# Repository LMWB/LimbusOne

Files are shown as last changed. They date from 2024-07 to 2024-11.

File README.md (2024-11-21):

# LimbusOne
Custom Microcontroller Board based on STM32F042-Series

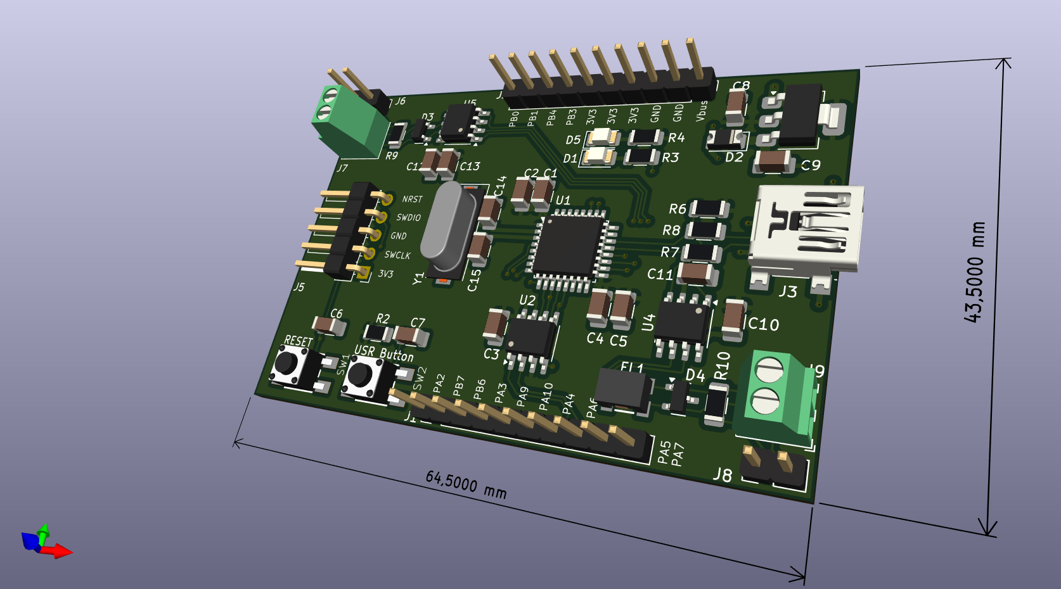
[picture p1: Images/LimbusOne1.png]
front

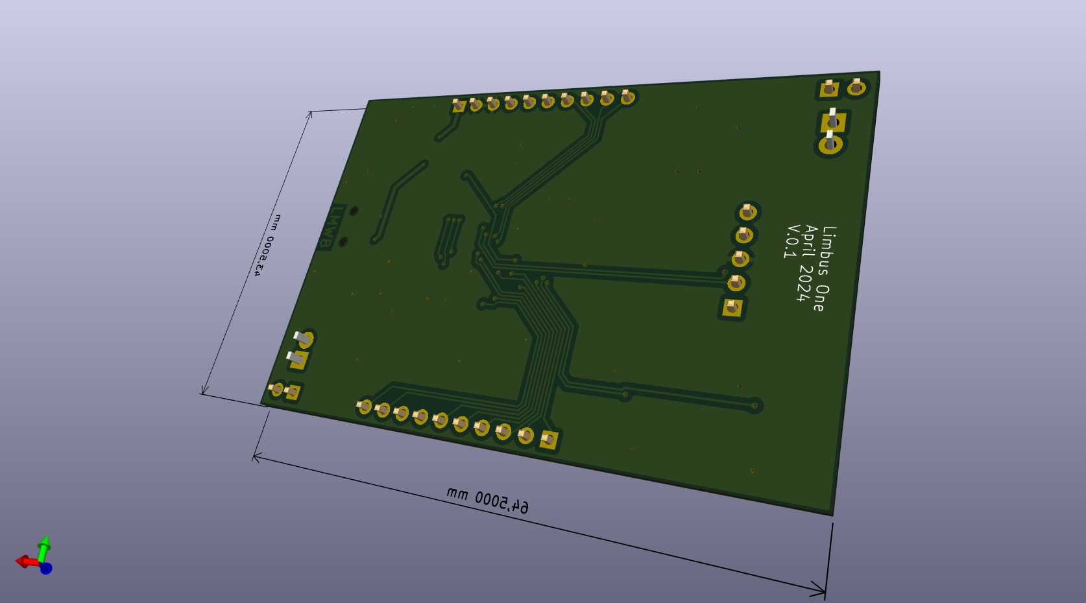
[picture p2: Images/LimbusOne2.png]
back

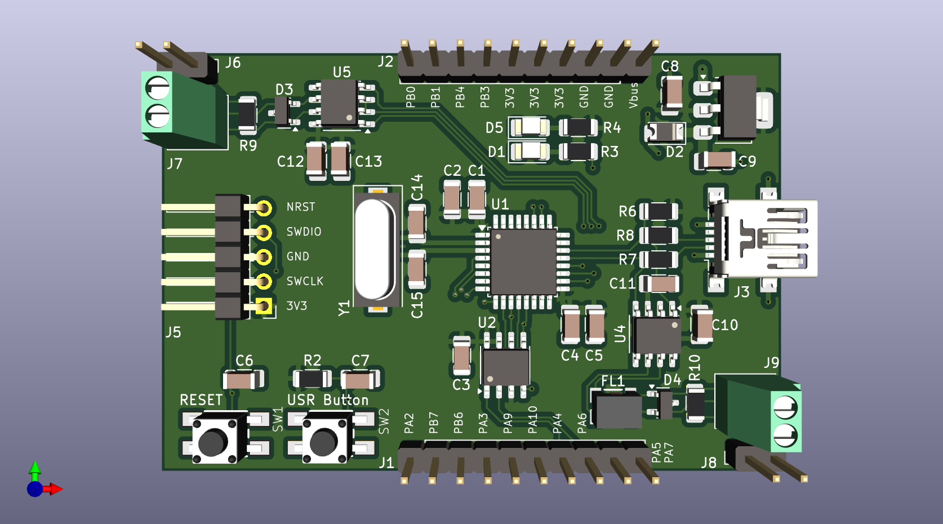
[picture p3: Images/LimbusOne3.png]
top

[schematics](/Hardware/LimbusOne/PDF/LimbusOne.pdf)

 Features
- STM32F042K6T6 Microcontroller
- it got a crystal oscillator but I did not use it
    - accuracy is good since USB Data is working
- Power indicator LED
- User LED
- User Push Button
- Industrial ready CAN-Bus interface
    - works with standard (11-Bit) and extended (29-Bit) CAN identifier
- Industrial ready Modbus interface
- USB mini as power supply AND DATA
    - unfortunately USB and CAN share same Pin's so the user has to decide what to use
- 2.54mm Pin Headers for debugging and tracing
- debug / programming interface according to STLink that comes with most of STM32 Nucleo Boards

# Todo
- adjust Pin Header spacing to a more usable spacing, right know its pretty random

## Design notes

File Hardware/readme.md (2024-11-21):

here you can find the KiCad EDA project files

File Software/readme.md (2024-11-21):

Here you can find some cubeIDE stand alone projects to test the hardware.
- basic to test flash capability Button, LED and Reset
- USB
- RS485 / Modbus
- CAN

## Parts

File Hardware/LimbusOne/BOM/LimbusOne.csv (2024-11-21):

Reference | Value | Footprint | Qty | DNP
C1,C4,C11,C13 | 47u | Capacitor_SMD:C_1206_3216Metric | 4
C2,C3,C5,C6,C7,C10,C12 | 100n | Capacitor_SMD:C_1206_3216Metric | 7
C8,C9 | 1u | Capacitor_SMD:C_1206_3216Metric | 2
C14,C15 | 22p | Capacitor_SMD:C_1206_3216Metric | 2
D1,D5 | LED | LED_SMD:LED_1206_3216Metric | 2
D2 | D | Diode_SMD:D_1206_3216Metric | 1
D3,D4 | NUP2105L | Package_TO_SOT_SMD:SOT-23 | 2
FL1 | Filter_CAN_Choke_LL_1234 | LMWB_footprints:WE-CNSW_1812 | 1
J1,J2 | Conn_01x10 | Connector_PinHeader_2.54mm:PinHeader_1x10_P2.54mm_Vertical | 2
J3 | USB_B_Micro | Connector_USB:USB_Mini-B_Lumberg_2486_01_Horizontal | 1
J5 | Conn_01x05 | Connector_PinHeader_2.54mm:PinHeader_1x05_P2.54mm_Horizontal | 1
J6,J7,J8,J9 | Conn_01x02 | -- mixed values -- | 4
R1,R2 | 10k | Resistor_SMD:R_1206_3216Metric | 2
R3,R4 | 220 | Resistor_SMD:R_1206_3216Metric | 2
R6 | 1k5 | Resistor_SMD:R_1206_3216Metric | 1
R7,R8 | 20 | Resistor_SMD:R_1206_3216Metric | 2
R9,R10 | 120 | Resistor_SMD:R_1206_3216Metric | 2
SW1,SW2 | SW_MEC_5E | LMWB_footprints:430181038816 | 2
U1 | STM32F042K6Tx | Package_QFP:LQFP-32_7x7mm_P0.8mm | 1
U2 | AT25xxx | Package_SO:SOIC-8_3.9x4.9mm_P1.27mm | 1
U3 | AMS1117-3.3 | Package_TO_SOT_SMD:SOT-223-3_TabPin2 | 1
U4 | TCAN334 | Package_SO:SOIC-8_3.9x4.9mm_P1.27mm | 1
U5 | MAX481E | Package_SO:SOIC-8_3.9x4.9mm_P1.27mm | 1
Y1 | Crystal | Crystal:Crystal_SMD_HC49-SD | 1

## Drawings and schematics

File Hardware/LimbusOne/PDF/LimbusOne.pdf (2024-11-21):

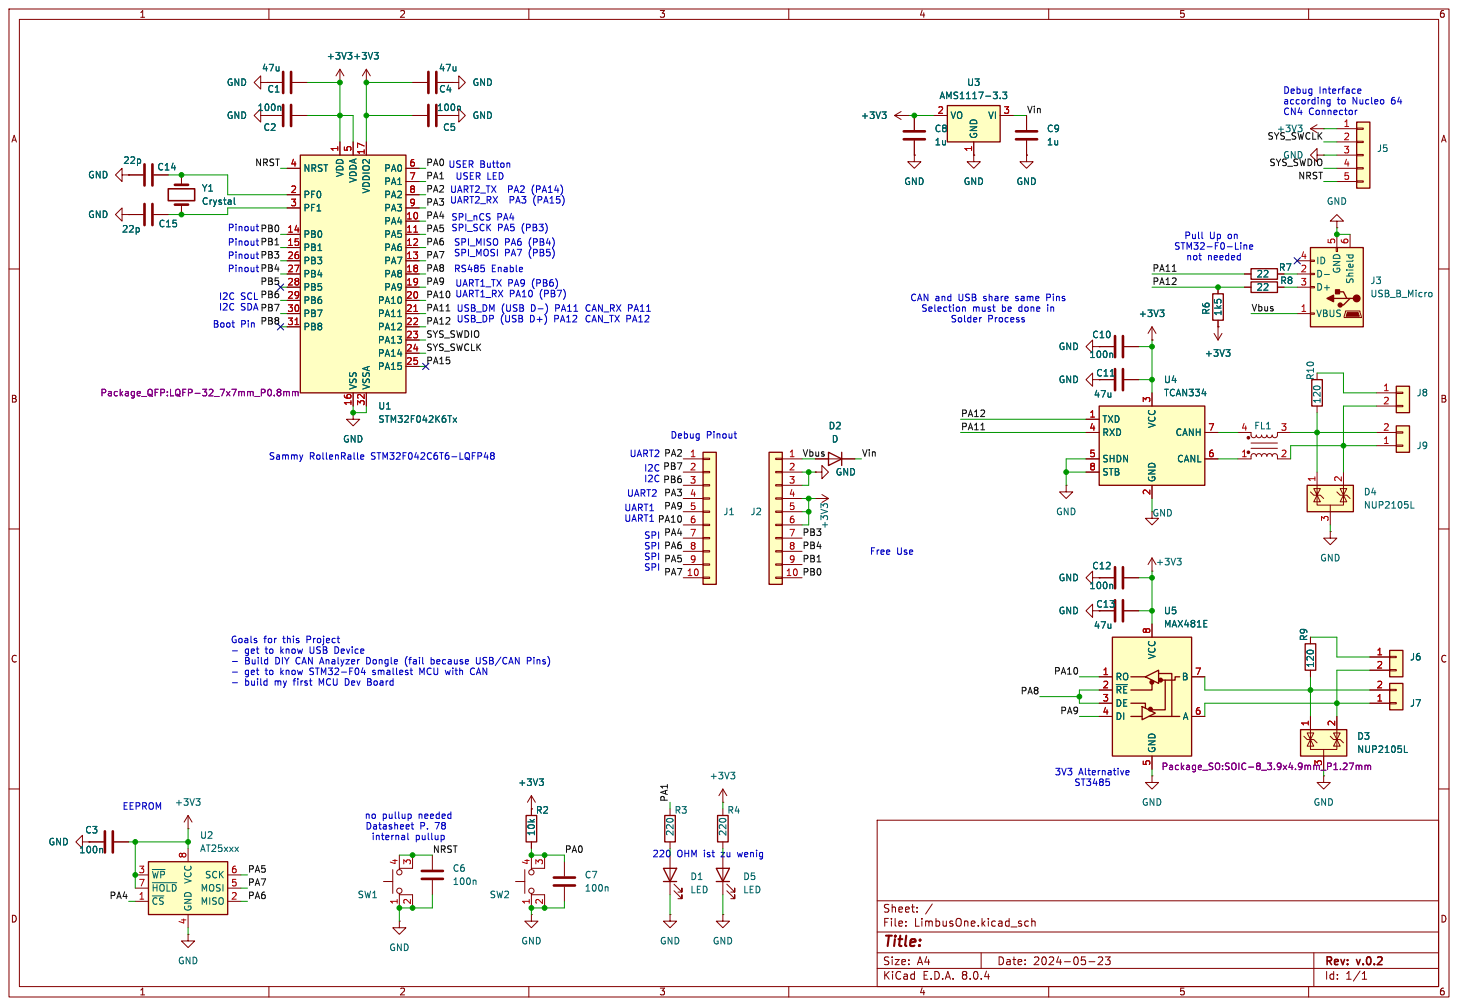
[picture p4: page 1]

1 PA4 10 PA5 11 PA6 12 PA7 13 PB0 14 PB1 15 VSS 16 VDDIO2 17 PA8 18 PA9 19 PF0 2 PA10 20 PA11 21 PA12 22 PA13 23 PA14 24 PA15 25 PB3 26 PB4 27 PB5 28 PB6 29 PF1 3 PB7 30 PB8 31 VSSA 32 NRST 4 VDDA

3 RXD 4 SHDN 5 CANL 6 CANH 7 STB 8 U4 TCAN334 C3

3 RXD 4 SHDN 5 CANL 6 CANH 7 STB 8 GND

- Build DIY CAN Analyzer Dongle (fail because USB/CAN Pins)

220 OHM ist zu wenig

4 MOSI 5 SCK 6 ~{HOLD} 7 VCC

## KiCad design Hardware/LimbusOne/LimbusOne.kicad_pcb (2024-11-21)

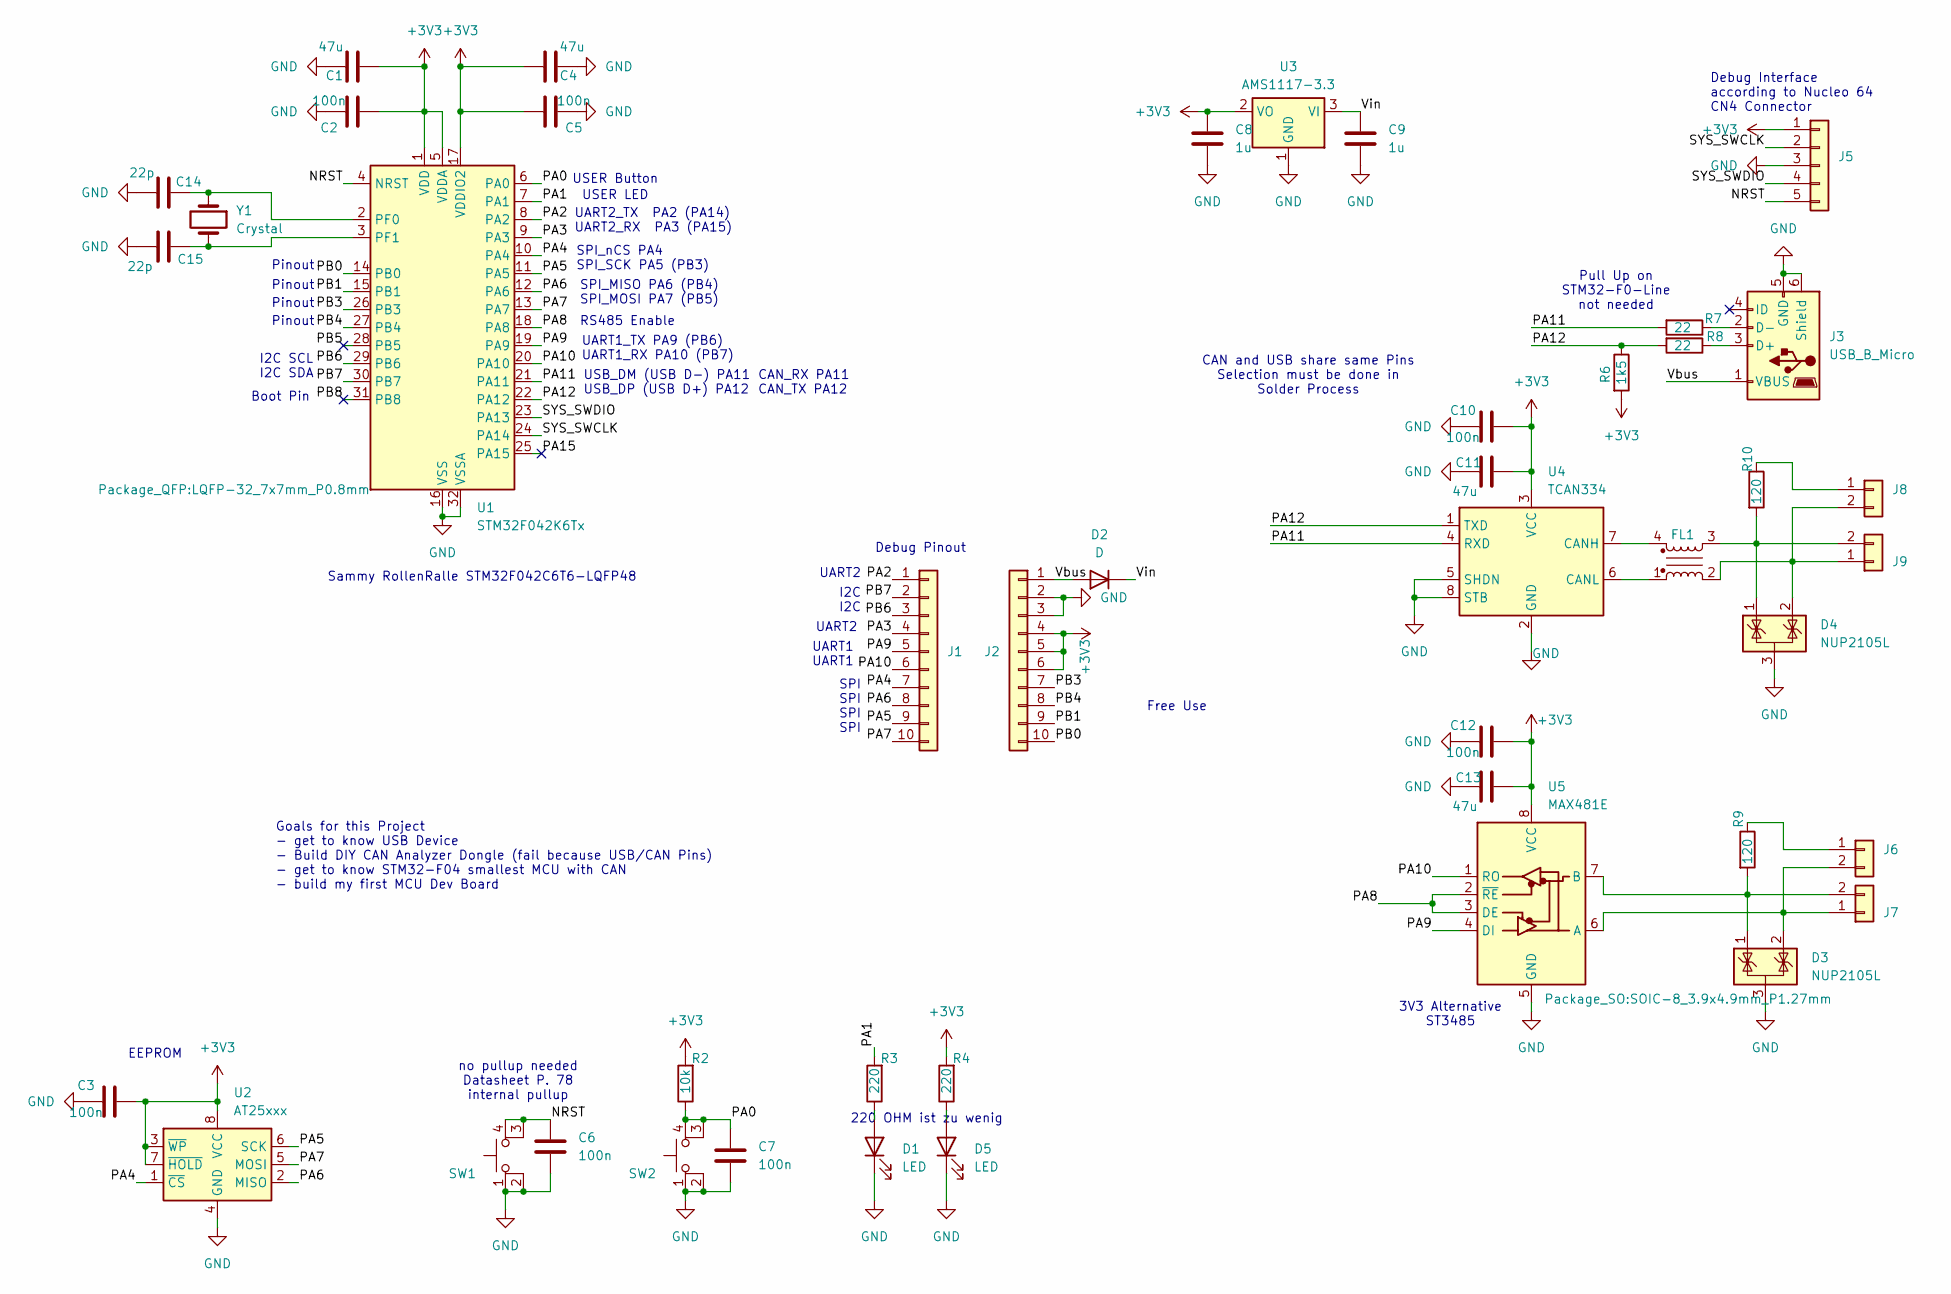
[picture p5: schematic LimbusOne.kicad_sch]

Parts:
C1, C4, C11, C13: 47u; C_1206_3216Metric
C2, C3, C5, C6, C7, C10, C12: 100n; C_1206_3216Metric
C8, C9: 1u; C_1206_3216Metric
C14, C15: 22p; C_1206_3216Metric
D1, D5: LED; LED_1206_3216Metric
D2: D; D_1206_3216Metric
D3, D4: NUP2105L; SOT-23
FL1: Filter_CAN_Choke_LL_1234; WE-CNSW_1812
J1, J2: Conn_01x10; PinHeader_1x10_P2.54mm_Vertical
J3: USB_B_Micro; USB_Mini-B_Lumberg_2486_01_Horizontal
J5: Conn_01x05; PinHeader_1x05_P2.54mm_Horizontal
J6, J8: Conn_01x02; PinHeader_1x02_P2.54mm_Vertical
J7, J9: Conn_01x02; TerminalBlock_Phoenix_MPT-0,5-2-2.54_1x02_P2.54mm_Horizontal
R2: 10k; R_1206_3216Metric
R3, R4: 220; R_1206_3216Metric
R6: 1k5; R_1206_3216Metric
R7, R8: 22; R_1206_3216Metric
R9, R10: 120; R_1206_3216Metric
SW1, SW2: SW_MEC_5E; 430181038816
U1: STM32F042K6Tx; LQFP-32_7x7mm_P0.8mm
U2: AT25xxx; SOIC-8_3.9x4.9mm_P1.27mm
U3: AMS1117-3.3; SOT-223-3_TabPin2
U4: TCAN334; SOIC-8_3.9x4.9mm_P1.27mm
U5: MAX481E; SOIC-8_3.9x4.9mm_P1.27mm
Y1: Crystal; Crystal_SMD_HC49-SD

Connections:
+3V3: C1.2, C2.2, C3.2, C4.2, C5.2, C8.1, C10.2, C11.2, C12.2, C13.2, J2.4, J2.5, J2.6, J5.1, R2.2, R4.2, R6.2, U1.1 (VDD), U1.5 (VDDA), U1.17 (VDDIO2), U2.3 (~WP), U2.7 (~HOLD), U2.8 (VCC), U3.2 (VO), U4.3 (VCC), U5.8 (VCC)
/NRST: C6.1, J5.5, SW1.3 (K), SW1.4 (A), U1.4 (NRST)
/PA0: C7.1, R2.1, SW2.3 (K), SW2.4 (A), U1.6 (PA0)
/PA1: R3.2, U1.7 (PA1)
/PA2: J1.1, U1.8 (PA2)
/PA3: J1.4, U1.9 (PA3)
/PA4: J1.7, U1.10 (PA4), U2.1 (~CS)
/PA5: J1.9, U1.11 (PA5), U2.6 (SCK)
/PA6: J1.8, U1.12 (PA6), U2.2 (MISO)
/PA7: J1.10, U1.13 (PA7), U2.5 (MOSI)
/PA8: U1.18 (PA8), U5.2 (~RE), U5.3 (DE)
/PA9: J1.5, U1.19 (PA9), U5.4 (DI)
/PA10: J1.6, U1.20 (PA10), U5.1 (RO)
/PA11: R7.2, U1.21 (PA11), U4.4 (RXD)
/PA12: R6.1, R8.2, U1.22 (PA12), U4.1 (TXD)
/PA15: U1.25 (PA15)
/PB0: J2.10, U1.14 (PB0)
/PB1: J2.9, U1.15 (PB1)
/PB3: J2.7, U1.26 (PB3)
/PB4: J2.8, U1.27 (PB4)
/PB5: U1.28 (PB5)
/PB6: J1.3, U1.29 (PB6)
/PB7: J1.2, U1.30 (PB7)
/PB8: U1.31 (PB8)
/SYS_SWCLK: J5.2, U1.24 (PA14)
/SYS_SWDIO: J5.4, U1.23 (PA13)
/Vbus: D2.2 (A), J2.1, J3.1 (VBUS)
/Vin: C9.1, D2.1 (K), U3.3 (VI)
GND: C1.1, C2.1, C3.1, C4.1, C5.1, C6.2, C7.2, C8.2, C9.2, C10.1, C11.1, C12.1, C13.1, C14.1, C15.1, D1.1 (K), D3.3 (A), D4.3 (A), D5.1 (K), J2.2, J2.3, J3.5 (GND), J3.6 (Shield), J5.3, SW1.1, SW1.2, SW2.1, SW2.2, U1.16 (VSS), U1.32 (VSSA), U2.4 (GND), U3.1 (GND), U4.2 (GND), U4.5 (SHDN), U4.8 (STB), U5.5 (GND)
unnamed: D1.2 (A), R3.1
unnamed: D5.2 (A), R4.1
unnamed: J3.3 (D+), R8.1
unnamed: J3.2 (D-), R7.1
unnamed: J6.1, R9.1
unnamed: D3.2 (K), J6.2, J7.1, U5.6 (A)
unnamed: D3.1 (K), J7.2, R9.2, U5.7 (B)
unnamed: J8.1, R10.1
unnamed: D4.2 (K), FL1.2, J8.2, J9.1
unnamed: D4.1 (K), FL1.3, J9.2, R10.2
unnamed: C14.2, U1.2 (PF0), Y1.1
unnamed: C15.2, U1.3 (PF1), Y1.2
unnamed: FL1.4, U4.7 (CANH)
unnamed: FL1.1, U4.6 (CANL)

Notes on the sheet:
RS485 Enable
Goals for this Project - get to know USB Device - Build DIY CAN Analyzer Dongle (fail because USB/CAN Pins) - get to know STM32-F04 smallest MCU with CAN - build my first MCU Dev Board
Free Use
SPI SPI SPI SPI
Pinout
USB_DM (USB D-) PA11 USB_DP (USB D+) PA12
Sammy RollenRalle STM32F042C6T6-LQFP48
USER LED
USER Button
3V3 Alternative ST3485
I2C I2C
Boot Pin
I2C SCL I2C SDA
Debug Pinout
UART1 UART1
UART1_TX PA9 (PB6) UART1_RX PA10 (PB7)
SPI_MISO PA6 (PB4) SPI_MOSI PA7 (PB5)
UART2_TX PA2 (PA14) UART2_RX PA3 (PA15)
UART2
220 OHM ist zu wenig
EEPROM
CAN and USB share same Pins Selection must be done in Solder Process
CAN_RX PA11 CAN_TX PA12
Debug Interface according to Nucleo 64 CN4 Connector
no pullup needed Datasheet P. 78 internal pullup
Pull Up on STM32-F0-Line not needed
SPI_nCS PA4 SPI_SCK PA5 (PB3)

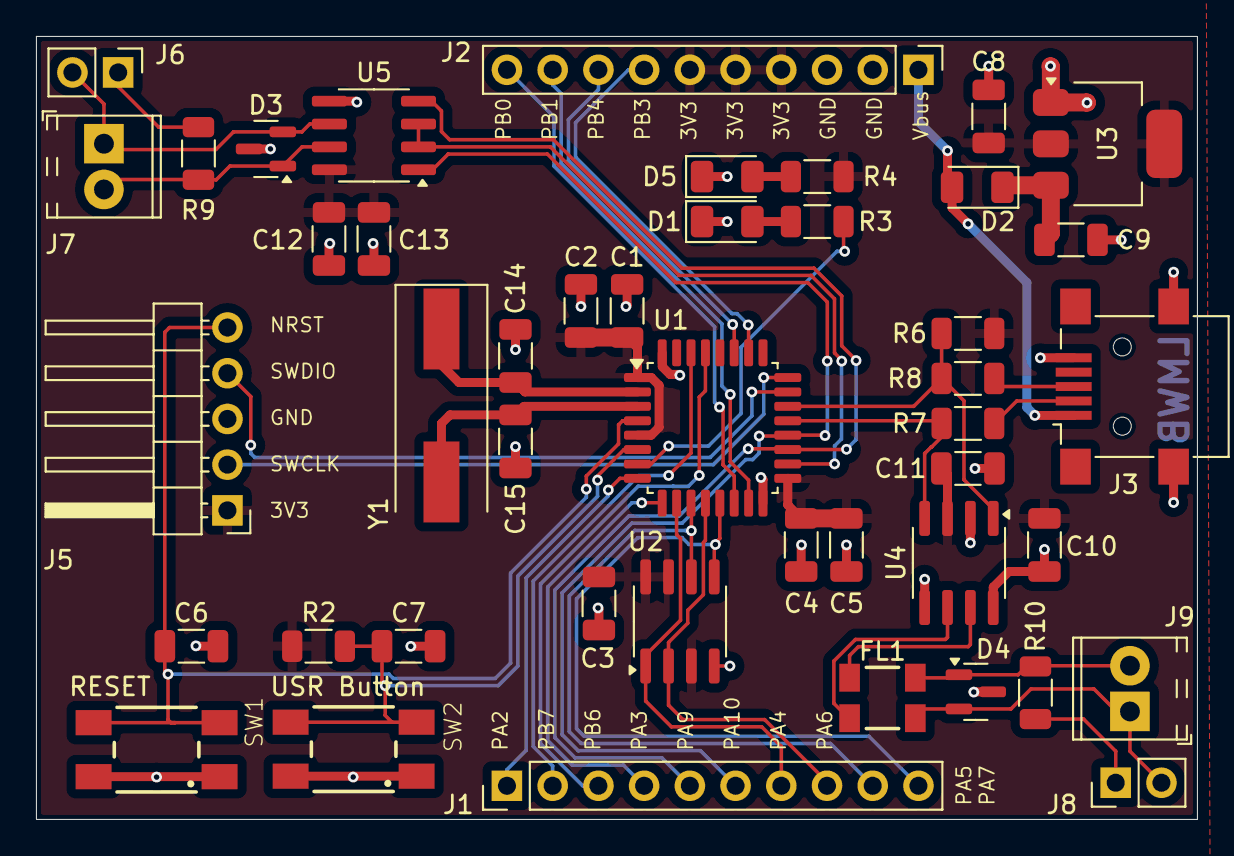
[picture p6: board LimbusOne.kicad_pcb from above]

Board: 2 copper layers, 64.5 x 43.5 mm, 45 parts (0 on the bottom side), 40 nets.

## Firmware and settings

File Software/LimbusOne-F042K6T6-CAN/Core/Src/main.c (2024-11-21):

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
/* Includes ------------------------------------------------------------------*/
#include "main.h"
#include "can.h"
#include "usart.h"
#include "gpio.h"


void SystemClock_Config(void);
/**
  * @brief  The application entry point.
  * @retval int
  */
int main(void)
{

  /* MCU Configuration--------------------------------------------------------*/

  /* Reset of all peripherals, Initializes the Flash interface and the Systick. */
  HAL_Init();

  /* Configure the system clock */
  SystemClock_Config();

  /* Initialize all configured peripherals */
  MX_GPIO_Init();
  MX_CAN_Init();
  MX_USART1_UART_Init();
  MX_USART2_UART_Init();
  /* USER CODE BEGIN 2 */

	// 1) init can -> done in cube mx
	// 2) configure can filter -> no filters for this demo all can messages are allowed to pass
  	  CAN_FilterTypeDef sFilterConfig;
  	  sFilterConfig.FilterMode = CAN_FILTERMODE_IDMASK;
  	  sFilterConfig.FilterScale = CAN_FILTERSCALE_32BIT;
  	  sFilterConfig.FilterIdHigh = 0x00;
  	  sFilterConfig.FilterIdLow = 0x00;
  	  sFilterConfig.FilterMaskIdHigh = 0x0;
  	  sFilterConfig.FilterMaskIdLow = 0x0;
  	  sFilterConfig.FilterFIFOAssignment = CAN_RX_FIFO0;
  	  sFilterConfig.FilterActivation = ENABLE;
  	  sFilterConfig.FilterBank = 0;
  	  HAL_CAN_ConfigFilter( &hcan, &sFilterConfig );

	// 3) activate interrupts
  	  HAL_StatusTypeDef can_state = 0;
  	can_state = HAL_CAN_ActivateNotification(&hcan, CAN_IT_RX_FIFO0_MSG_PENDING);
  	can_state = HAL_CAN_ActivateNotification(&hcan, CAN_IT_RX_FIFO1_MSG_PENDING);
  	can_state = HAL_CAN_ActivateNotification(&hcan, CAN_IT_RX_FIFO0_FULL);
  	can_state = HAL_CAN_ActivateNotification(&hcan, CAN_IT_RX_FIFO0_OVERRUN);
  	can_state = HAL_CAN_ActivateNotification(&hcan, CAN_IT_ERROR);

	// 4) start can hardware
  	can_state = HAL_CAN_Start(&hcan);

  /* USER CODE END 2 */

  /* Infinite loop */
  /* USER CODE BEGIN WHILE */
	while (1) {
    /* USER CODE END WHILE */

    /* USER CODE BEGIN 3 */

		/*
		 * canID => CAN Identifier 11Bit or 29Bit
		 * extID => 0 = Standard, 1 = Extended
		 * aData = Payload, pointer to byte array
		 * DLC = Data length code, must be  <= 8
		 * */
		CAN_TxHeaderTypeDef sTxHeader;
		HAL_StatusTypeDef can_tx_rx_status;

		// choose standard or extended CAN identifier type
		uint8_t extID = 0;
		// choose CAN identifier
		uint32_t canID = 0x101;
		uint32_t tx_mailbox = 0;


		uint8_t DLC = 8;
		uint8_t aData[8] = { 'R', 'O', 'L', 'L', 'E', 'N', 'R', 'A'};

		if (extID) {
			sTxHeader.StdId = 0;
			sTxHeader.ExtId = canID;
			sTxHeader.IDE = CAN_ID_EXT;
		} else {
			sTxHeader.StdId = canID;
			sTxHeader.ExtId = 0;
			sTxHeader.IDE = CAN_ID_STD;
		}
		/* Data Length Code max. 8 byte */
		if (DLC <= 8) {
			sTxHeader.DLC = DLC;
		} else {
			sTxHeader.DLC = 8;
		}
		sTxHeader.RTR = CAN_RTR_DATA;
		sTxHeader.TransmitGlobalTime = DISABLE;
		can_tx_rx_status = HAL_CAN_AddTxMessage(&hcan, &sTxHeader, aData, &tx_mailbox);

		HAL_Delay(200);
		//HAL_GPIO_TogglePin(LED1_GPIO_Port, LED1_Pin);



	}
  /* USER CODE END 3 */
}

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
/* USER CODE BEGIN 4 */

// 5) action on CAN-RX-interrupt
void HAL_CAN_RxFifo0MsgPendingCallback(CAN_HandleTypeDef *hcan) {
	CAN_RxHeaderTypeDef sRxHeader = {0};
	HAL_StatusTypeDef tx_rx_status;
	uint8_t rx_data[8];
	if (hcan->Instance == CAN) {
		/* pick up incoming data and release the CAN Peripheral */
		tx_rx_status = HAL_CAN_GetRxMessage(hcan, CAN_RX_FIFO0, &sRxHeader, rx_data);

		// do stuff with header (metadata)
		sRxHeader.DLC;
		sRxHeader.ExtId;
		sRxHeader.FilterMatchIndex;
		sRxHeader.IDE;
		sRxHeader.RTR;
		sRxHeader.StdId;
		sRxHeader.Timestamp;

		// do stuff with payload

		// indicate something going on on can-interrupts
		HAL_GPIO_TogglePin(LED1_GPIO_Port, LED1_Pin);


	}
}

void HAL_CAN_RxFifo1MsgPendingCallback(CAN_HandleTypeDef *hcan) {
	// indicate something going on on can-interrupts
	//HAL_GPIO_TogglePin(LED1_GPIO_Port, LED1_Pin);
}

void HAL_CAN_RxFifo0FullCallback(CAN_HandleTypeDef *hcan) {
	// todo
	//HAL_GPIO_TogglePin(LED1_GPIO_Port, LED1_Pin);
}

void HAL_CAN_ErrorCallback(CAN_HandleTypeDef *hcan) {
	uint32_t error = hcan->ErrorCode;
	// todo
	//HAL_GPIO_TogglePin(LED1_GPIO_Port, LED1_Pin);
}

/* USER CODE END 4 */
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


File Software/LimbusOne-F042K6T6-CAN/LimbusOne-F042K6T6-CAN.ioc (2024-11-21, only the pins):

Mcu.UserName=STM32F042K6Tx
PA1.GPIO_Label=LED1
PA1.Signal=GPIO_Output
PA10.Signal=USART1_RX
PA11.Signal=CAN_RX
PA12.Signal=CAN_TX
PA13.Signal=SYS_SWDIO
PA14.Signal=SYS_SWCLK
PA2.Signal=USART2_TX
PA3.Signal=USART2_RX
PA9.Signal=USART1_TX

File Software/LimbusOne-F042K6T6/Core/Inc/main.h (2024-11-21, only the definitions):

#define LED1_Pin GPIO_PIN_1
#define LED1_GPIO_Port GPIOA
#define RS485_Enable_Pin GPIO_PIN_8
#define RS485_Enable_GPIO_Port GPIOA

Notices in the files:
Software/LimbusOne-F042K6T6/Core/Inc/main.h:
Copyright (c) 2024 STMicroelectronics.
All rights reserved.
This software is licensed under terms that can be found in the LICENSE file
